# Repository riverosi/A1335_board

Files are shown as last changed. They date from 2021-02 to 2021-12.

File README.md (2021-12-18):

# A1335_board Project v1
Reposiorio de la pcb que usa el sensor [A1335](https://www.allegromicro.com/en/products/sense/linear-and-angular-position/angular-position-sensor-ics/a1335) de Allegro. Esta vesión tiene los siguientes requerimientos:
- [x] Los capacitores de desacople van a ir cerca del integrado
- [x] La mascara tendra una simbologia con la asigancion de pines
- [x] No se usaran las anotaciones en el cobre
- [x] Dimensiones propuestas: 50x40 mm
- [x] Se usaran pines como conectores
- [x] Tendrá 4 mountingholes tamaño M3
Vistas 3d del PCB:

<p align="center">
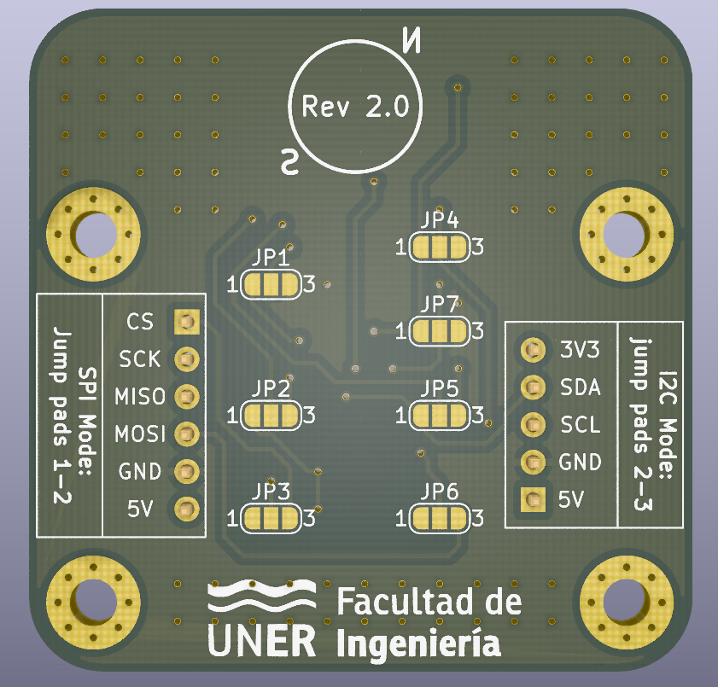
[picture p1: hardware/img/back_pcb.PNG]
  
</p>
<p align="center">
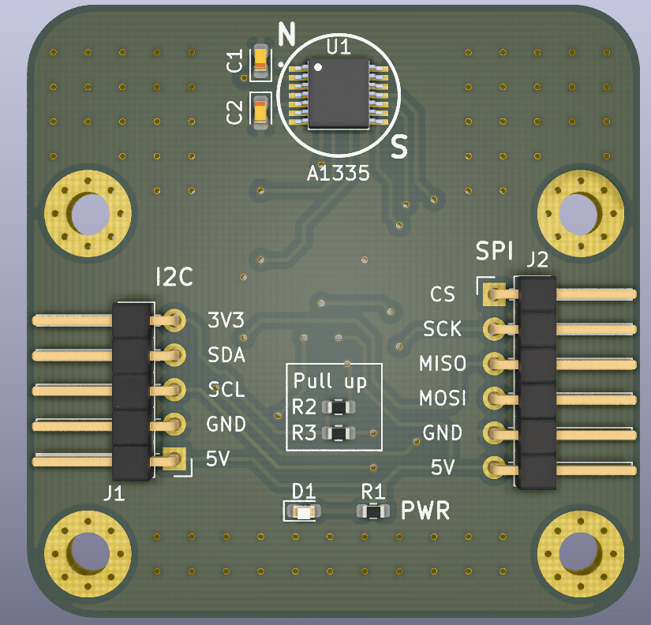
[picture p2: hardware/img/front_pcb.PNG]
  
</p>

# Montaje final del PCB con el Bumper:

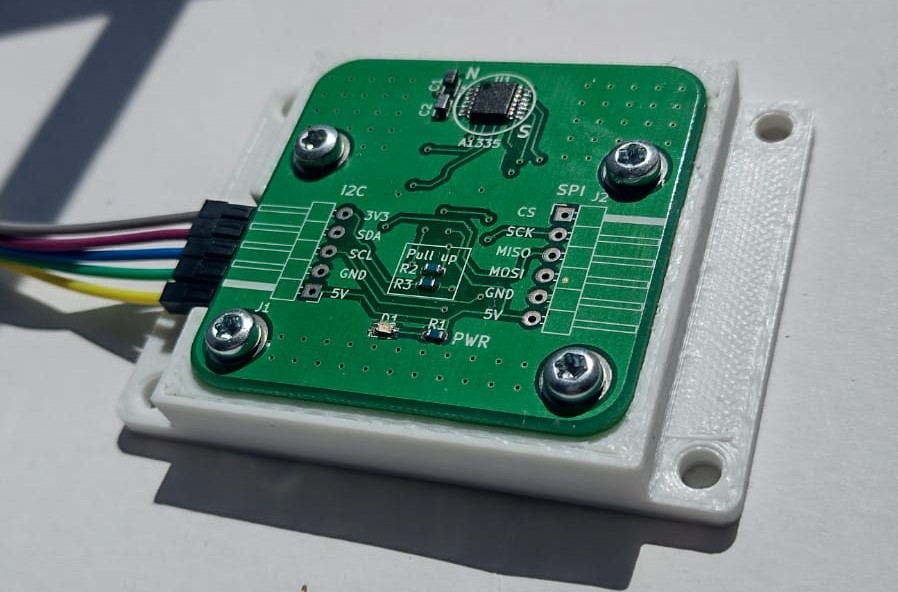
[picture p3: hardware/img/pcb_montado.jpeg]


## Firmware
En la carpeta firmware están los archivos `__angle_driver.h` y `__angle_driver.c`, que son los drivers en c para la plataforma de desarollo EDU-CIAA. En el main hay un ejemplo de como inicializar el dispositivo con las direcciones correspondientes al hardware que se desarrollo en la v1 (0x0C). 

## Software
Para desarrollar la placa se uso:
* [Doxygen](https://www.doxygen.nl/index.html) - To generate the documentation
* [VSCode](https://code.visualstudio.com/) - To communicate data through the UART (Developing)
* [KiCad](https://kicad.org/) - To develop de board

## Hardware
Para desarrollar la placa se uso **Kicad**, se debe de incluir la libraria HALL con el simbolo del componente A1335.

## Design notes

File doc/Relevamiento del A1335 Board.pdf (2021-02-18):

# Relevamiento del A1335 Board

## Circuito:

El circuito es el propuesto por la nota de aplicación de allegro para comunicación serial por I2C.

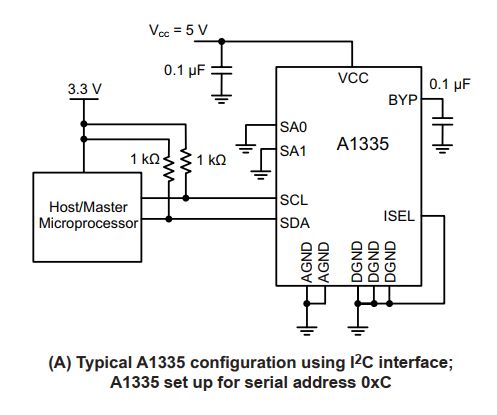
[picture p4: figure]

## Configuración del puerto:

Características del Puerto de comunicación I2C | Observación
Address | 0xC aunque el mismo es configurable usando los jumpers de la pcb
CLK | 100 kHz

## Conexionado y colores de los cables:

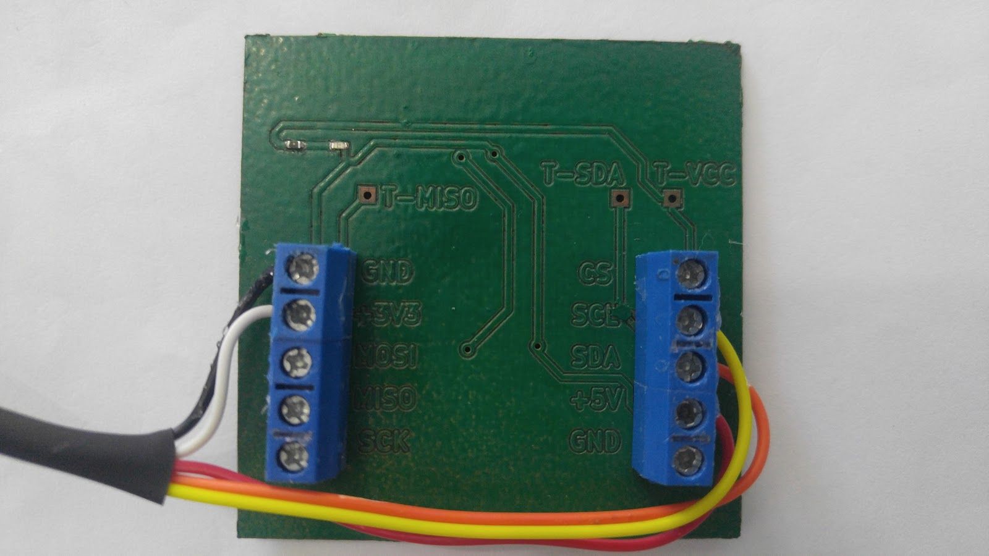
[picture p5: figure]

## A revisar:

- Dejar agujeros para montaje en la pcb
- El LED de indicación de encendido está del lado contrario al montaje general de todos los componentes
- Si vamos a hacer en chica necesitamos generar una máscara con la señalética de pines y componentes.
- Subir al repositorio.
- No usar borneras, sino pines hembras para reducir espacio en pcb
- Evaluar la impresión 3d de un soporte para que la plaqueta no quede en contacto directo con la estructura
Pin del A1335 Board | Cable
5V | Rojo
SCL | Amarillo
SDA | Naranja
GND | Negro
3V3 | Blanco

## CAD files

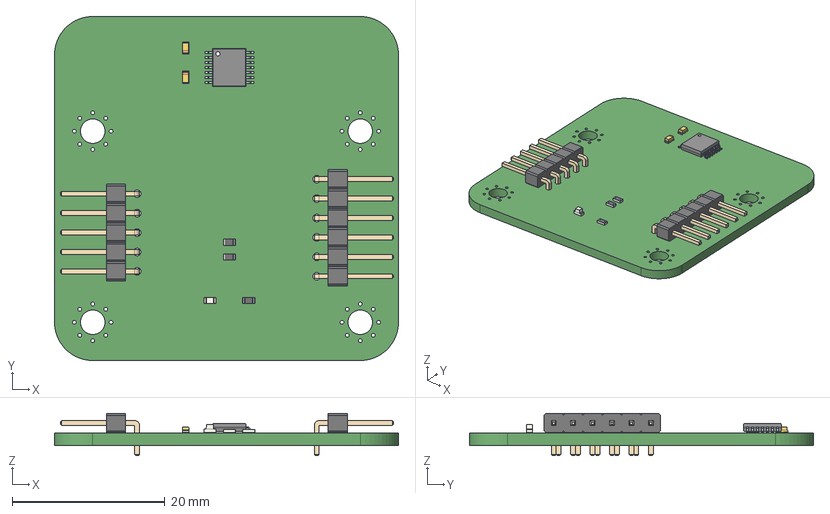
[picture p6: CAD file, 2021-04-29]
hardware/1335_rev1.step
45.0 x 45.0 x 5.54 mm

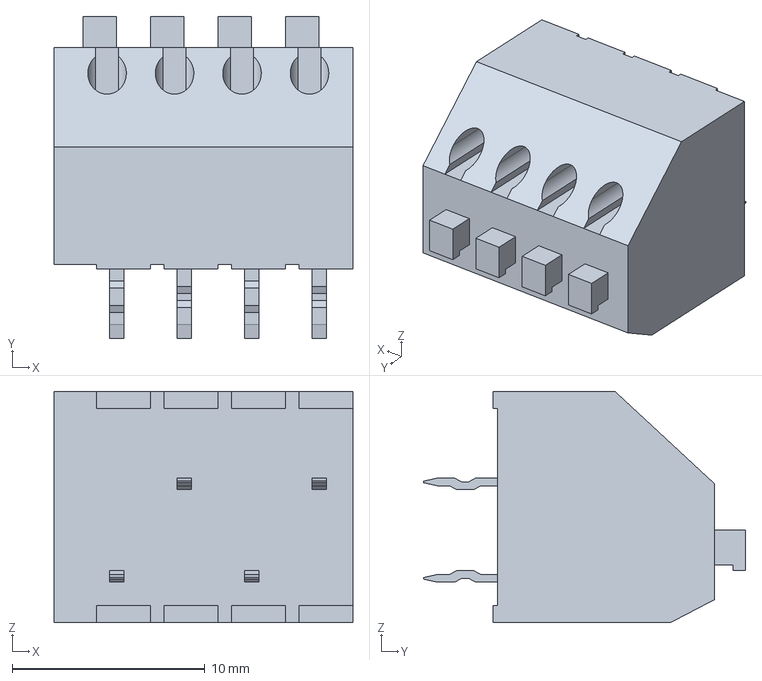
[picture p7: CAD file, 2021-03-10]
hardware/1335_rev1/Models_3d/250-204.stp
15.5 x 16.7 x 12.0 mm

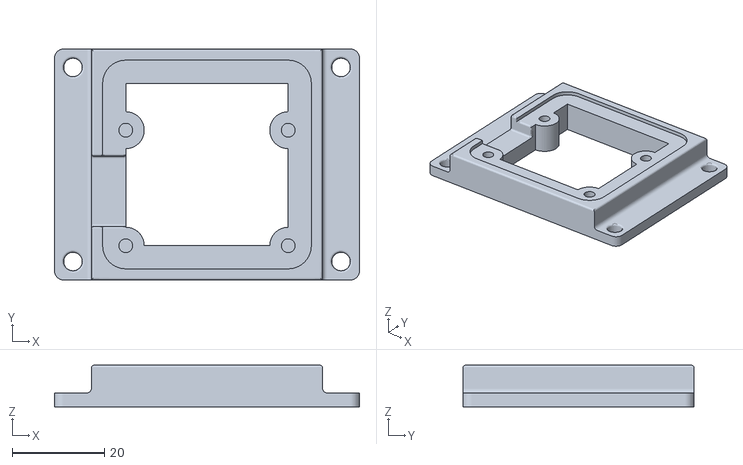
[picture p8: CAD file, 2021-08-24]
hardware/bumper3D/Bumper_pcb v9.stl
66.0 x 50.0 x 9.00

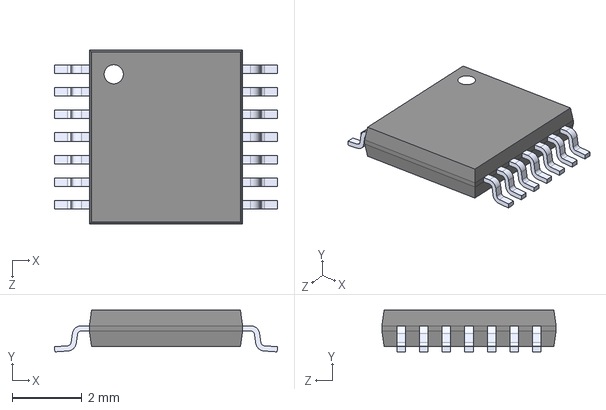
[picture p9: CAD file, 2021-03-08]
hardware/1335_rev1/Models_3d/BQ34110PW.STEP
6.40 x 1.20 x 5.00 mm

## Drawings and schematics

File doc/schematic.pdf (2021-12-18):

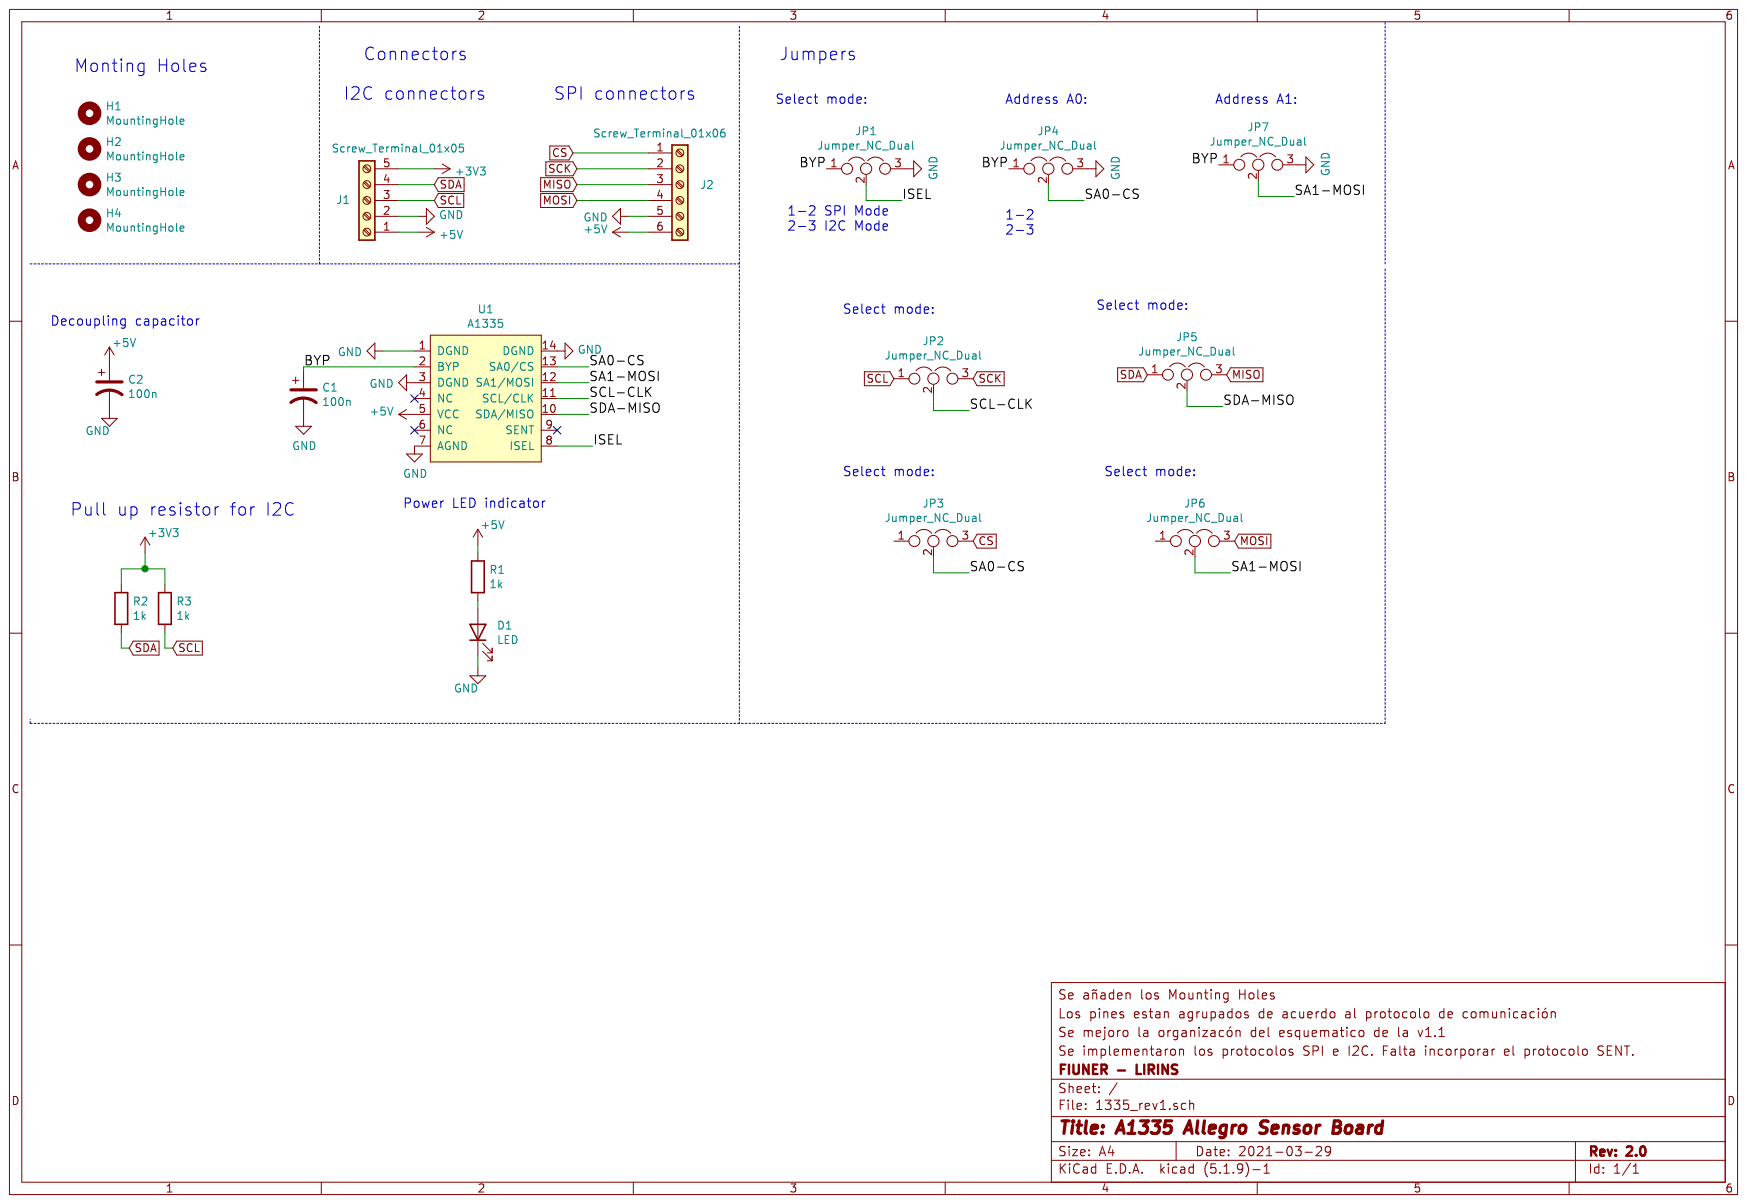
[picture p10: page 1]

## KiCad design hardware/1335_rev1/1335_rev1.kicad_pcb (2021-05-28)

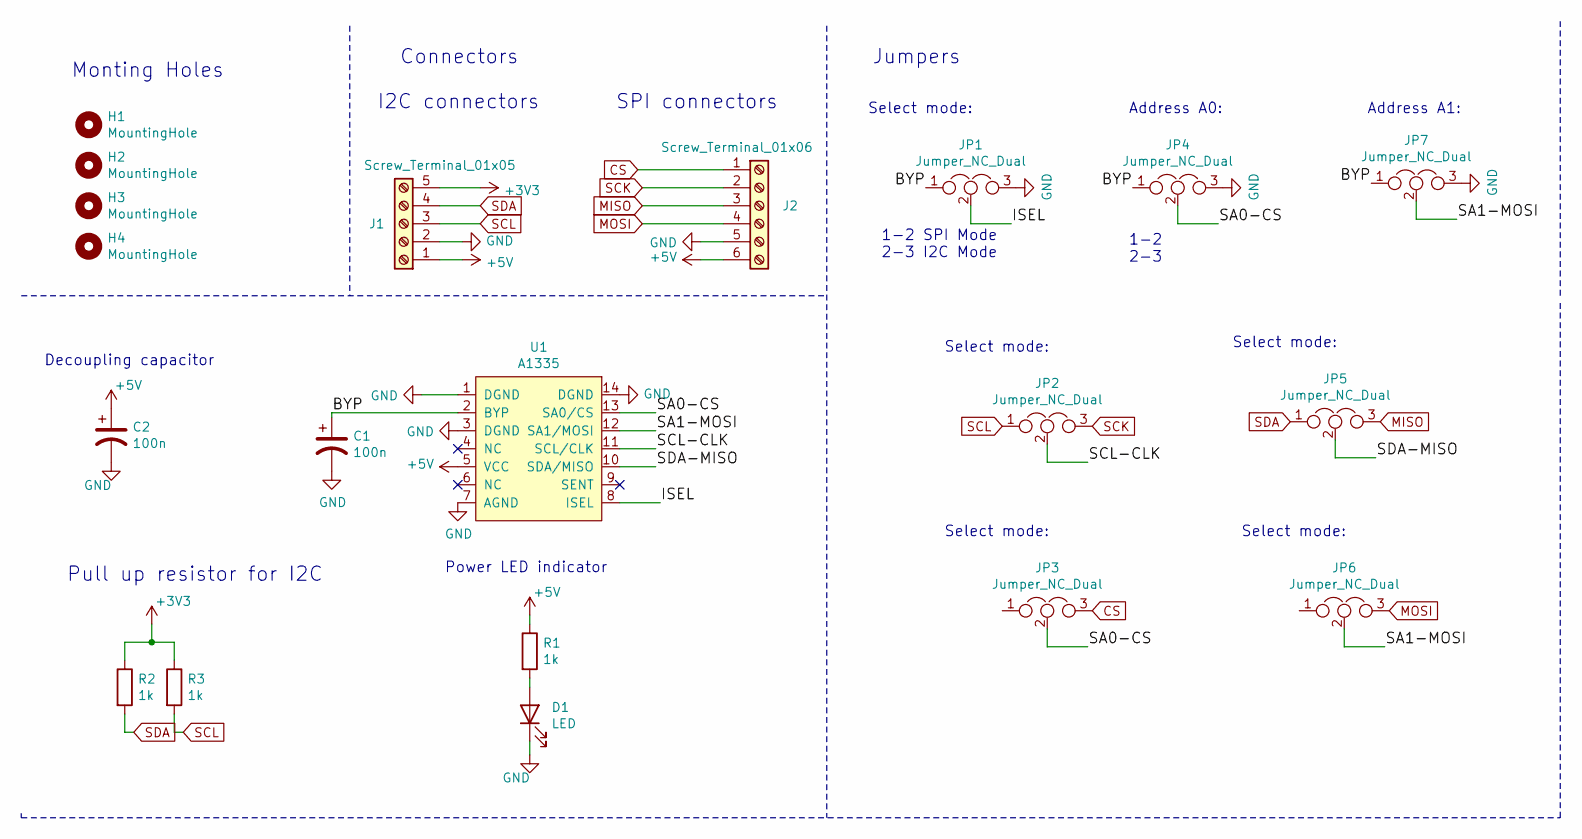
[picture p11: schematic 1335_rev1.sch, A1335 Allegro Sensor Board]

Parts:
C1, C2: 100n; CP_EIA-2012-15_AVX-P_Pad1.30x1.05mm_HandSolder
D1: LED; LED_0603_1608Metric
H1, H2, H3, H4: MountingHole; MountingHole_3.2mm_M3_Pad_Via
J1: Screw_Terminal_01x05; PinHeader_1x05_P2.54mm_Horizontal
J2: Screw_Terminal_01x06; PinHeader_1x06_P2.54mm_Horizontal
JP1, JP2, JP3, JP4, JP5, JP6, JP7: Jumper_NC_Dual; SolderJumper-3_P1.3mm_Open_RoundedPad1.0x1.5mm_NumberLabels
R1, R2, R3: 1k; R_0603_1608Metric
U1: A1335; TSSOP14

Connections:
+3V3: J1.5, R2.1, R3.1
+5V: C2.1, J1.1, J2.6, R1.1, U1.5 (VCC)
/BYP: C1.1, JP1.1, JP4.1, JP7.1, U1.2 (BYP)
/ISEL: JP1.2, U1.8 (ISEL)
/SA0-CS: JP3.2, JP4.2, U1.13 (SA0/CS)
/SA1-MOSI: JP6.2, JP7.2, U1.12 (SA1/MOSI)
/SCL-CLK: JP2.2, U1.11 (SCL/CLK)
/SDA-MISO: JP5.2, U1.10 (SDA/MISO)
CS: J2.1, JP3.3
GND: C1.2, C2.2, D1.1 (K), J1.2, J2.5, JP1.3, JP4.3, JP7.3, U1.1 (DGND), U1.3 (DGND), U1.7 (AGND), U1.14 (DGND)
MISO: J2.3, JP5.3
MOSI: J2.4, JP6.3
unnamed: D1.2 (A), R1.2
SCK: J2.2, JP2.3
SCL: J1.3, JP2.1, R3.2
SDA: J1.4, JP5.1, R2.2

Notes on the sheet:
Monting Holes
Jumpers
Select mode:
Connectors
Address A0:
Address A1:
Decoupling capacitor
I2C connectors
SPI connectors
1-2 SPI Mode 2-3 I2C Mode
1-2 2-3
Pull up resistor for I2C
Power LED indicator

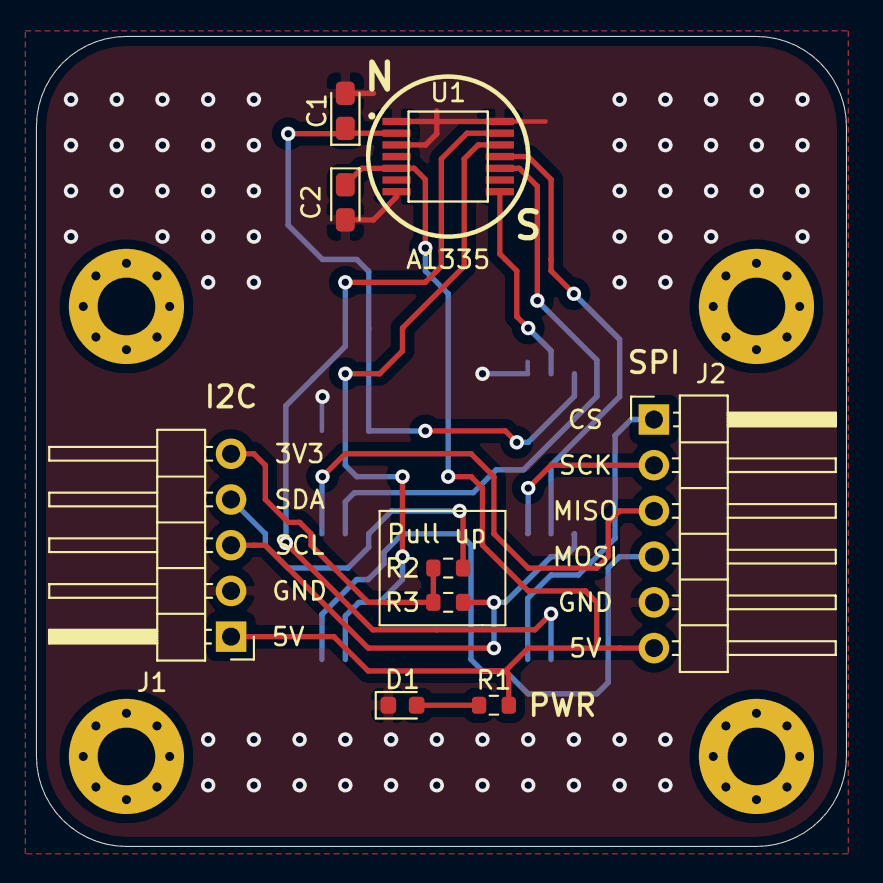
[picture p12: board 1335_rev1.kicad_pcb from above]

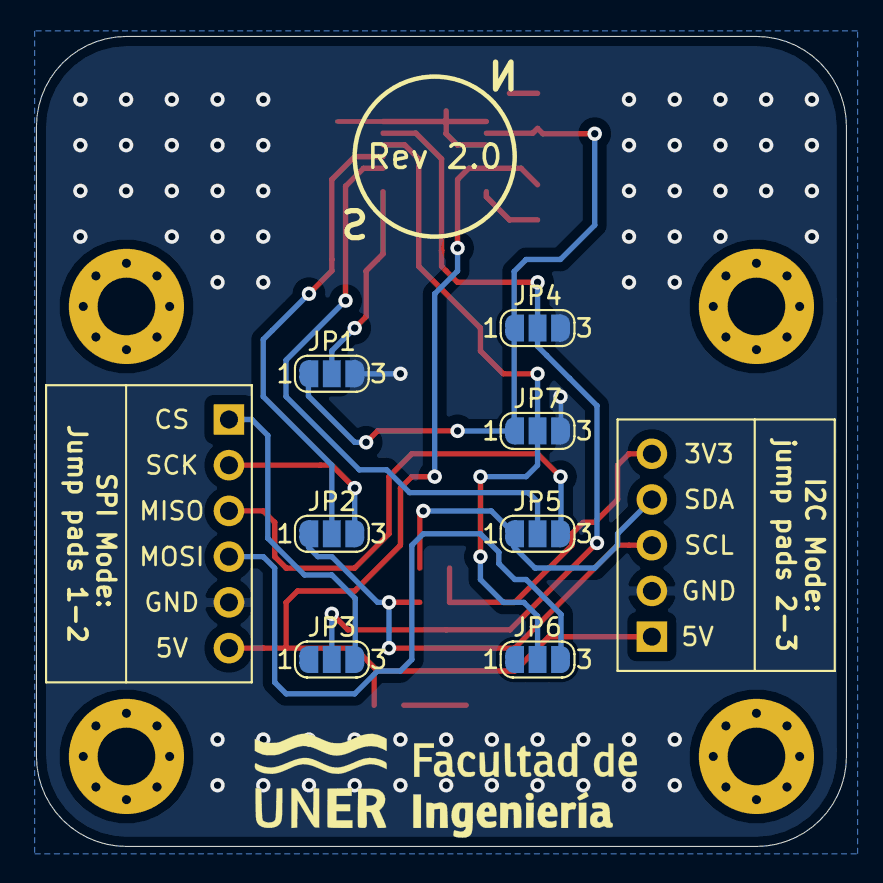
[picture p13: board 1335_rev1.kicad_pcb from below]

Board: 2 copper layers, 45.0 x 45.0 mm, 20 parts (7 on the bottom side), 16 nets.

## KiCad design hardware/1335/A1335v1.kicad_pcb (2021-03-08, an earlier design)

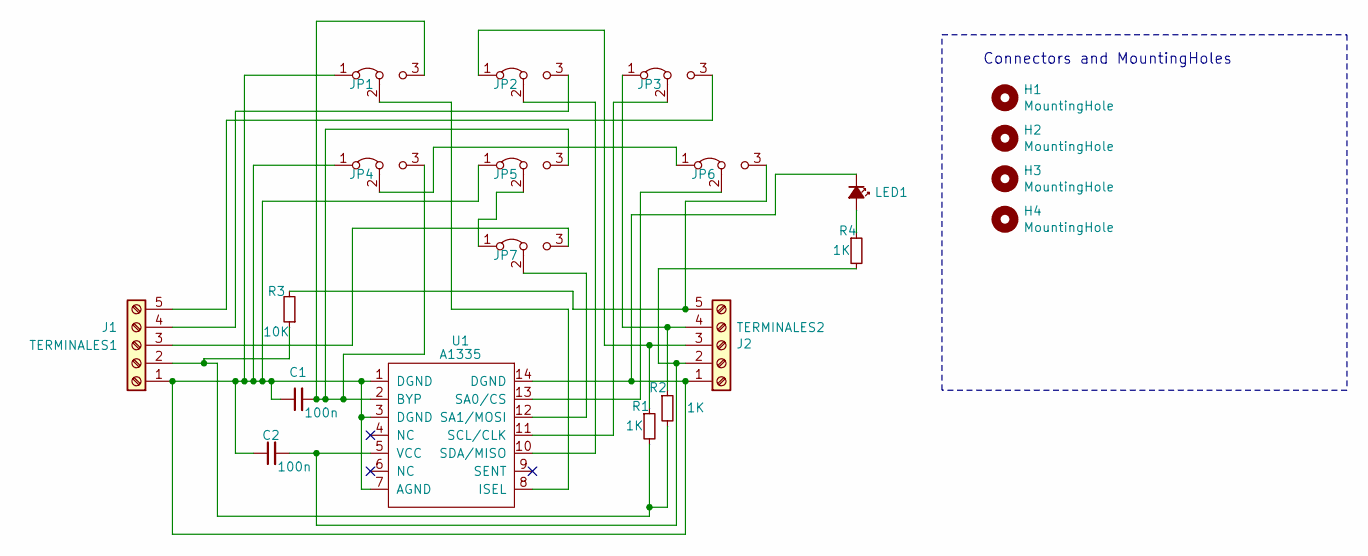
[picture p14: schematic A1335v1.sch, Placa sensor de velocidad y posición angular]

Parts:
C1, C2: 100n; CP_EIA-1608-08_AVX-J
H1, H2, H3, H4: MountingHole; MountingHole_3.2mm_M3_Pad_Via
J1: TERMINALES1; terminal_block_1x05_45DEG_3.81MM_5POS
J2: TERMINALES2; terminal_block_1x05_45DEG_3.81MM_5POS
JP1: 1; SolderJumper-3_P1.3mm_Bridged2Bar12_Pad1.0x1.5mm
JP2: 2; SolderJumper-3_P1.3mm_Bridged2Bar12_Pad1.0x1.5mm
JP3: 3; SolderJumper-3_P1.3mm_Bridged2Bar12_Pad1.0x1.5mm
JP4: 4; SolderJumper-3_P1.3mm_Bridged2Bar12_Pad1.0x1.5mm
JP5: 5; SolderJumper-3_P1.3mm_Bridged2Bar12_Pad1.0x1.5mm
JP6: 6; SolderJumper-3_P1.3mm_Bridged2Bar12_Pad1.0x1.5mm
JP7: 7; SolderJumper-3_P1.3mm_Bridged2Bar12_Pad1.0x1.5mm
LED1: LED; LED_0603_1608Metric
R1, R2, R4: 1K; R_0603_1608Metric
R3: 10K; R_0603_1608Metric
U1: A1335

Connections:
unnamed: C1.1, C2.1, J1.1, J2.1, JP1.1 (A), JP4.1 (A), JP5.1 (A), LED1.1 (K), U1.1 (DGND), U1.3 (DGND), U1.7 (AGND), U1.14 (DGND)
unnamed: C1.2, JP1.3 (B), JP4.3 (B), JP5.3 (B), U1.2 (BYP)
unnamed: C2.2, J2.2, R4.2, U1.5 (VCC)
unnamed: J1.2, R1.2, R2.2, R3.1
unnamed: J1.3, JP7.3 (B)
unnamed: J1.4, JP2.3 (B)
unnamed: J1.5, JP3.3 (B)
unnamed: J2.3, JP2.1 (A), R1.1
unnamed: J2.4, JP3.1 (A), R2.1
unnamed: J2.5, JP6.3 (B), R3.2
unnamed: JP1.2 (C), U1.8 (ISEL)
unnamed: JP2.2 (C), U1.10 (SDA/MISO)
unnamed: JP3.2 (C), U1.11 (SCL/CLK)
unnamed: JP4.2 (C), JP6.1 (A)
unnamed: JP5.2 (C), JP7.1 (A)
unnamed: JP6.2 (C), U1.13 (SA0/CS)
unnamed: JP7.2 (C), U1.12 (SA1/MOSI)
unnamed: LED1.2 (A), R4.1

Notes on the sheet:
Connectors and MountingHoles

Board: 2 copper layers, 20 parts (0 on the bottom side), 13 nets, no tracks yet.

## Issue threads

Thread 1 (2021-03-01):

# A1335 New Board:

riverosi, 2021-03-01:
- [x] Dejar agujeros para montaje en la pcb
- [x] El LED de indicación de encendido está del lado contrario al montaje general de todos los componentes
- [x] Si vamos a hacer en chica necesitamos generar una máscara con la señalética de pines y componentes.
- [x] Subir al repositorio.
- [x] No usar borneras, sino pines para reducir espacio en pcb
- [x] Evaluar la impresión 3d de un soporte para que la plaqueta no quede en contacto directo con la estructura y evitar usar pegamento

riverosi, 2021-03-01:
# Consideraciones para la v2:
## Del esquematico:

- [ ] usar etiquetas en vez de los wires (no se entiende nada)
- [ ] pasos para incluir a la libreria el a1335
- [ ] Eliminar los test point
- [ ] El led puede ser tht
- [ ] USAR COMPONENTES DE UN SOLO LADO!
- [ ] Resistencia de 1k para un led a 5v?

## Del diseño:
- [ ] Los capacitores de desacople deben ir cerca del integrado
- [ ] La mascara debe estar completa
- [ ] Evitar las anotaciones en el cobre
- [ ] Dimensiones propuestas: 50x40 mm
- [ ] Las borneras no se justifican propongo usar pines
- [ ] mounting holes insolated or in GND?

Closed 2021-08-24.

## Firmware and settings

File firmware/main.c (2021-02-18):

/* Copyright 2018, Eduardo Filomena - Gonzalo Cuenca
 * All rights reserved.
 *
 * This file is part of CIAA Firmware.
 *
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
 * 3. Neither the name of the copyright holder nor the names of its
 *    contributors may be used to endorse or promote products derived from this
 *    software without specific prior written permission.
 *
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
 */

/** \brief Blinking Bare Metal example source file
 **
 ** This is a mini example of the CIAA Firmware.
 **
 **/

/** \addtogroup CIAA_Firmware CIAA Firmware
 ** @{ */

/** \addtogroup Examples CIAA Firmware Examples
 ** @{ */
/** \addtogroup Baremetal Bare Metal example source file
 ** @{ */

/*
 * Initials     Name
 * ---------------------------
 *
 */

/*
 * modification history (new versions first)
 * -----------------------------------------------------------
 * yyyymmdd v0.0.1 initials initial version
 */

/*==================[inclusions]=============================================*/
#include "../../app_nrf24l01/inc/mi_proyecto.h"       /* <= own header */
#include "systemclock.h"
#include <stdlib.h>
/*=====[Inclusions of function dependencies]=================================*/

/*=====[Definition macros of private constants]==============================*/
const uint32_t _ANGLE_I2C_CFG[1] = { 100000 };

/*=====[Definitions of extern global variables]==============================*/

/*=====[Definitions of public global variables]==============================*/

/*=====[Definitions of private global variables]=============================*/

/*=====[Main function, program entry point after power on or reset]==========*/
uint32_t cnt = 0;
void SysTick_Handler(void) {
	if (cnt == 500) {
		GPIOToggle(LEDRGB_B);
		cnt = 0;
	}
	cnt++;
}
int main(void) {

	/* perform the needed initialization here */
	SystemClockInit();
	fpuInit();
	StopWatch_Init();
	Init_Uart_Ftdi(115200);
	Init_Leds();
	angle_i2cDriverInit(_ANGLE_I2C_CFG[0], 0x0C);
	angle_setConfig(
			_ANGLE_CDS_NO_CHANGLE | _ANGLE_HDR_RESET_1 | _ANGLE_SFR_RESET_1
					| _ANGLE_CSR_STA_1 | _ANGLE_CXE_1 | _ANGLE_CER_1);
	SysTick_Config(SystemCoreClock / 1000);/*call systick every 1ms*/
	uint16_t Angle;
	char buffer_string[5];
	// ----- Repeat for ever -------------------------
	while (TRUE) {
		Angle = angle_getAngle();
		itoa((int)Angle, buffer_string, 10);
		Chip_UART_SendBlocking(USB_UART, buffer_string, 5);
		Chip_UART_SendBlocking(USB_UART, "\n", 1);
		GPIOToggle(LEDRGB_G);
		StopWatch_DelayMs(100);

		__WFI();
	}

	// YOU NEVER REACH HERE, because this program runs directly or on a
	// microcontroller and is not called by any Operating System, as in the
	// case of a PC program.

	return 0;

}

/** @} doxygen end group definition */
/** @} doxygen end group definition */
/** @} doxygen end group definition */
/*==================[end of file]============================================*/

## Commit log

2021-02-18 Add firmware
    [A1335v1.2.kicad_pcb, A1335v1.sch]
2021-03-01 Begin Revision of board
    Add mounting holes and changes in connectors
2021-03-08 add a1335_rev2 files
    [1335_rev1.kicad_pcb, 1335_rev1.sch, A1335v1.kicad_pcb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]
2021-03-10 Add 3d models, send to review pcb
    [1335_rev1.kicad_pcb, 1335_rev1.sch, 250-204.stp]
2021-03-17 Add connectors and pull up resistors
    [1335_rev1.kicad_pcb, 1335_rev1.sch]
2021-03-21 Add F.sliks anotations
    [1335_rev1.kicad_pcb, 1335_rev1.sch]
2021-03-29 Updates in pcb
    [1335_rev1-B_Cu.gbr, 1335_rev1-B_Mask.gbr, 1335_rev1-B_Paste.gbr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]
2021-04-13 Send to review
    Esteban Osella aprueba el diseño del PCB
    [1335_rev1.kicad_pcb, 1335_rev1.sch, file606D0E9F.sch]
2021-04-21 Change position of mh
    [1335_rev1 Border.gbr, 1335_rev1 Bottom Silk.gbr, 1335_rev1 Botton Layer.gbr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]
2021-04-29 Generate gerber files
    [1335_rev1 Bottom Silk.gbr, 1335_rev1-Border.gbr, 1335_rev1-Bottom_Layer.gbr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]
2021-05-28 Error in boom
    [1335_rev1.kicad_pcb, 1335_rev1.sch]
2021-08-24 Add 3D bumper
    [Bumper_pcb v9.stl]
2021-12-18 Add Schematic
